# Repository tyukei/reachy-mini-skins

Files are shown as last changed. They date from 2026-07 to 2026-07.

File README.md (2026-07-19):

# Reachy Mini printable skins

Removable, 3D-printable costume accessories for an assembled Reachy Mini.

## Skin collections

- [Ninja skin](ninja/README.md) — hood, torso armour, and headband tails
- [Pineapple skin](pineapple/README.md) — textured body wrap and leafy crown

Each collection contains ready-to-print STL files, an editable parametric Python generator, and printing and installation instructions.

## View an STL

Install `fstl` on Ubuntu with `sudo apt install fstl`, then run:

```bash
./view-stl.sh ninja/stl/reachy_mini_ninja_hood.stl
./view-stl.sh pineapple/stl/reachy_mini_pineapple_body_front.stl
```

You can also open the STL files directly in Cura, PrusaSlicer, or Bambu Studio.

## Regenerate the models

```bash
python3 -m venv .venv
.venv/bin/pip install -r requirements.txt
.venv/bin/python ninja/generate_ninja_skin.py
.venv/bin/python pineapple/generate_pineapple_skin.py
```

Reachy Mini is a Pollen Robotics/Hugging Face product. This costume project is unofficial.

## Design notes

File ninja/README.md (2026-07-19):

# Reachy Mini removable ninja skin

- `reachy_mini_ninja_hood.stl` — front-loading hood with a large face opening and antenna reliefs
- `reachy_mini_ninja_torso_front.stl` — ventilated front gi/armour with four elastic-strap slots
- `reachy_mini_ninja_headband_tails.stl` — optional decorative knot and tails

The fit dimensions were derived from the official Pollen Robotics Reachy Mini head and body STL files. The costume does not replace or modify structural robot parts.

## Print settings

- Material: PETG preferred; PLA is suitable for a display robot
- Layer height: 0.20 mm
- Walls: 3 perimeters
- Infill: 12–18%
- Hood: place the broad rear/open edge on the build plate; organic/tree supports only under the brow if your slicer requests them
- Torso: print upright; use a brim if needed
- Tails: print flat and glue to the rear edge of the hood after test fitting

All STL units are millimetres. The largest part needs a build area of about 175 × 110 mm.

## Fit and installation

1. Print the hood first at normal scale. Slip it on from the front while the robot is powered off.
2. Confirm at least 1 mm clearance from the white head shell and full clearance around both animated antenna roots.
3. Fit the torso front with two 10 mm elastic or hook-and-loop straps through the four side slots. Do not tighten enough to deform the original shell.
4. Slowly exercise all head and body motion at low speed. Remove the skin if it touches the neck mechanism, antennas, camera, microphones, speaker openings, cables, or rotating base.

Do not cover ventilation or operate the robot unattended until a full motion/heat test has passed. Printer shrinkage varies; regenerate the hood with more clearance if it is tight:

```bash
python3 -m venv .venv
.venv/bin/pip install -r requirements.txt
.venv/bin/python ninja/generate_ninja_skin.py --clearance 1.5
```

The default hood has 1.0 mm nominal clearance and a 2.0 mm wall. The torso has 1.5 mm nominal radial clearance beyond the measured body-corner envelope.

## Design source

`ninja/generate_ninja_skin.py` is the editable parametric source. It exports only manifold, watertight meshes and stops if validation fails.

Reachy Mini is a Pollen Robotics/Hugging Face product. This costume project is unofficial.

## View the STL files

A local copy of `fstl` can be launched without administrator access:

```bash
./view-stl.sh ninja/stl/reachy_mini_ninja_hood.stl
./view-stl.sh ninja/stl/reachy_mini_ninja_torso_front.stl
```

Drag with the left mouse button to rotate, use the wheel to zoom, and right-drag to pan.

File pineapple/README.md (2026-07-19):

# Reachy Mini removable pineapple skin

The pineapple costume is split into two printable parts:

- `pineapple/stl/reachy_mini_pineapple_body_front.stl` — textured yellow body shell
- `pineapple/stl/reachy_mini_pineapple_leaf_crown.stl` — green leafy head crown

Both are accessories for an assembled robot; they do not replace structural parts.

## Printing

- Body: yellow PETG or PLA, upright, 0.20 mm layers, 3 walls, 12–18% infill
- Crown: green PETG or PLA, broad cap edge on the build plate, tree supports under leaves as needed
- Largest footprint: approximately 172 × 110 mm
- STL units: millimetres

The raised body diamonds are intentionally shallow so they print cleanly. The body shell includes four slots for 10 mm elastic or hook-and-loop straps and five airflow/audio vents.

## Connecting the front around the back

The pineapple body is intentionally a **front shell only**. There is no printed back shell. Two straps wrap around Reachy Mini's existing rear body and hold the printed front in place.

You need:

- Two 10 mm wide elastic or hook-and-loop straps
- Approximately 300–350 mm length per strap; trim after test fitting
- Optional small plastic buckles if you use plain elastic

Connection steps:

1. Feed one strap through the two upper side slots in the printed body shell.
2. Wrap the strap around the back of Reachy Mini and connect its ends with hook-and-loop or a buckle.
3. Repeat with the two lower slots and the second strap.
4. Center the printed shell on the front of the robot.
5. Tighten only enough to prevent the shell from sliding. Do not deform the original white body.

The open back preserves ventilation, leaves ports and cables accessible, and lets you remove the costume without disassembling the robot. Do not route a strap across a connector, speaker opening, ventilation opening, or moving seam.

## Installation and safety

1. Power Reachy Mini off.
2. Attach the body front loosely using the two straps described above. Do not deform the original body shell.
3. Slide the crown on from the front. Keep both circular side reliefs clear of the animated antenna roots.
4. Confirm the camera, microphones, speaker openings, neck, ventilation, and rotating base are unobstructed.
5. At low speed, test the full head, antenna, and body movement range. Remove either piece immediately if it touches a moving part.

Printer tolerances vary. To increase clearance, regenerate with:

```bash
python3 -m venv .venv
.venv/bin/pip install -r requirements.txt
.venv/bin/python pineapple/generate_pineapple_skin.py --head-clearance 1.5 --body-clearance 2.0
```

## Viewing

```bash
./view-stl.sh pineapple/stl/reachy_mini_pineapple_body_front.stl
./view-stl.sh pineapple/stl/reachy_mini_pineapple_leaf_crown.stl
```

The editable parametric source is `pineapple/generate_pineapple_skin.py`.

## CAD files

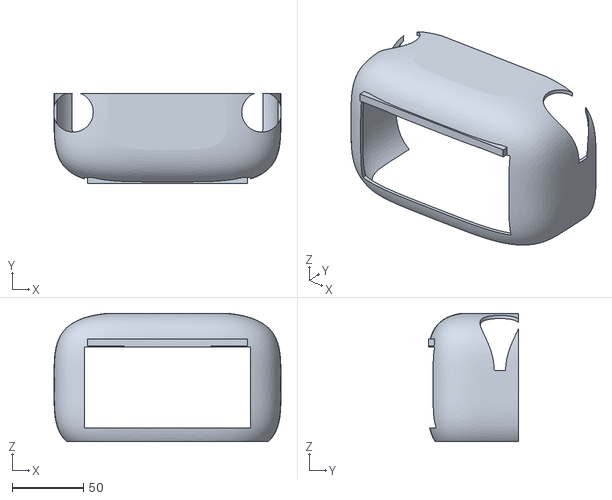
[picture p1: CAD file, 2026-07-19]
ninja/stl/reachy_mini_ninja_hood.stl
159.0 x 63.0 x 90.0

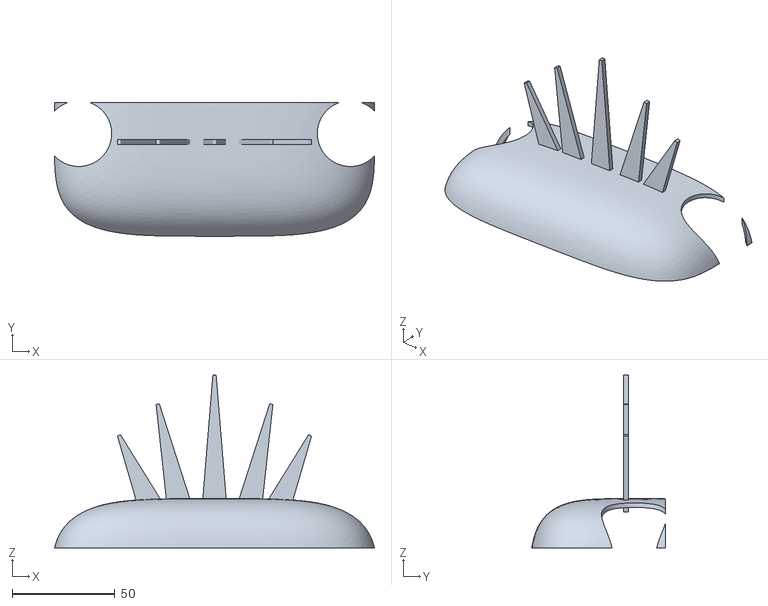
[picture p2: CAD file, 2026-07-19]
pineapple/stl/reachy_mini_pineapple_leaf_crown.stl
155.6 x 64.9 x 84.0

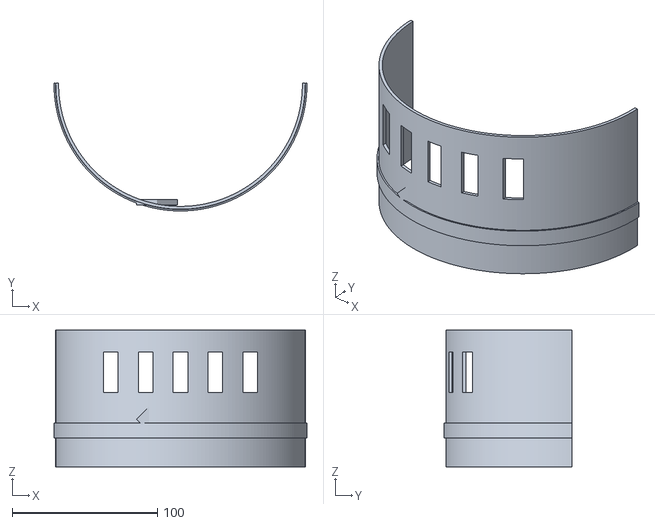
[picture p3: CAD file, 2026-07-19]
ninja/stl/reachy_mini_ninja_torso_front.stl
174.0 x 88.0 x 94.0

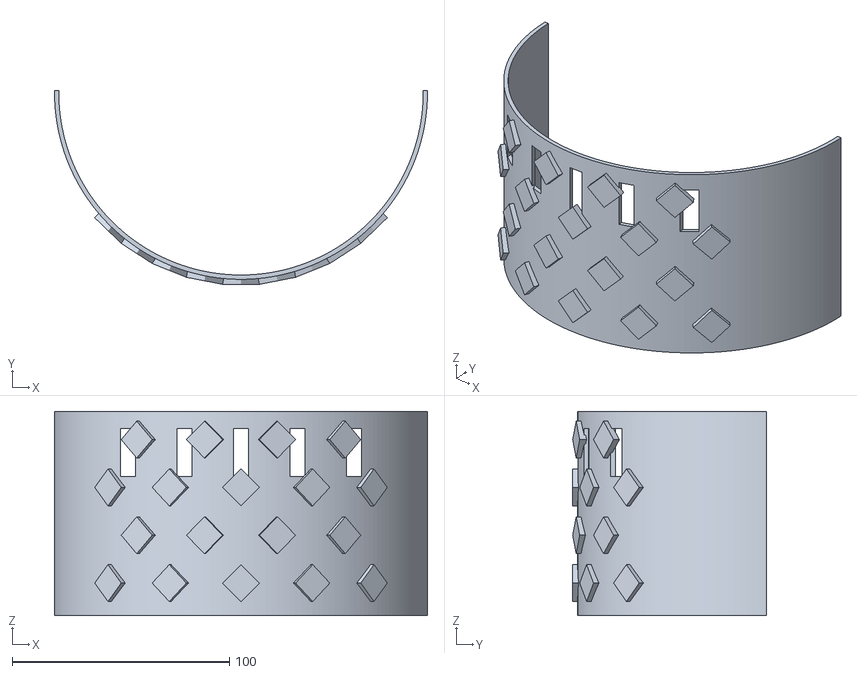
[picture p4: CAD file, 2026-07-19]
pineapple/stl/reachy_mini_pineapple_body_front.stl
171.6 x 89.1 x 94.0

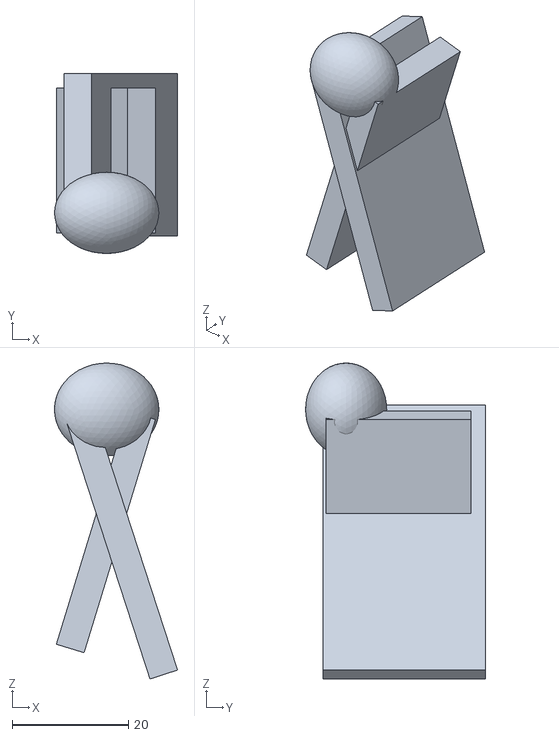
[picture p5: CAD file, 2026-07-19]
ninja/stl/reachy_mini_ninja_headband_tails.stl
21.2 x 31.0 x 54.4

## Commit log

2026-07-19 Add printable ninja and pineapple skins for Reachy Mini
    [reachy_mini_ninja_headband_tails.stl, reachy_mini_ninja_hood.stl, reachy_mini_ninja_torso_front.stl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]
2026-07-19 Organize skins into ninja and pineapple folders
    [reachy_mini_ninja_headband_tails.stl, reachy_mini_ninja_hood.stl, reachy_mini_ninja_torso_front.stl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]
